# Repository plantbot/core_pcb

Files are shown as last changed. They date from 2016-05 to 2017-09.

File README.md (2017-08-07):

# Open Plantbot

Because growing plants is hard work and nobody ain't got no time for that anymore. This project was started after I managed to kill a plant my mother got me for my birthday last year because it was "unkillable". Ha.

This project aims to build an open source tool that provides environmental sensors for regular house plants as well as hydroponic systems.

Monitoring can either be done locally or via a "cloud" or not at all with add-on ports for pumps and future expansions (or your own?).

The goal is to eventually provide a block-based programming interface so that even people who don't enjoy writing C code (tzzz...who doesn't? :P) can customise their plantbot to do what they want.

### Current specs

Here is a list of current specs with notes about how they integrate/ work

1x Wifi enabled microprocessor

 - Can be programmed via RX/TX serial lines
 - USB/ OTA programming will be added later

4x Analog sensor mounts (for temperature, soil moisture, light, ...)

 - Variable gain amplifier can be used on a per-channel basis
 - Signal offset results in optimal reading per sensor type
 
2x I²C expansion ports for additional sensors or expansions

16-pin shield header for user (or future) expansion boards

Low-power sleep mode for the entire board/ expansion circuitry

### Current state

The board was re-designed recently in Rev A2. Prototypes were ordered and partially assembled. Further testing on the board layout and circuit design needs to be performed.

The firmware is largely unwritten.

Following are some pictures. Enjoy :)

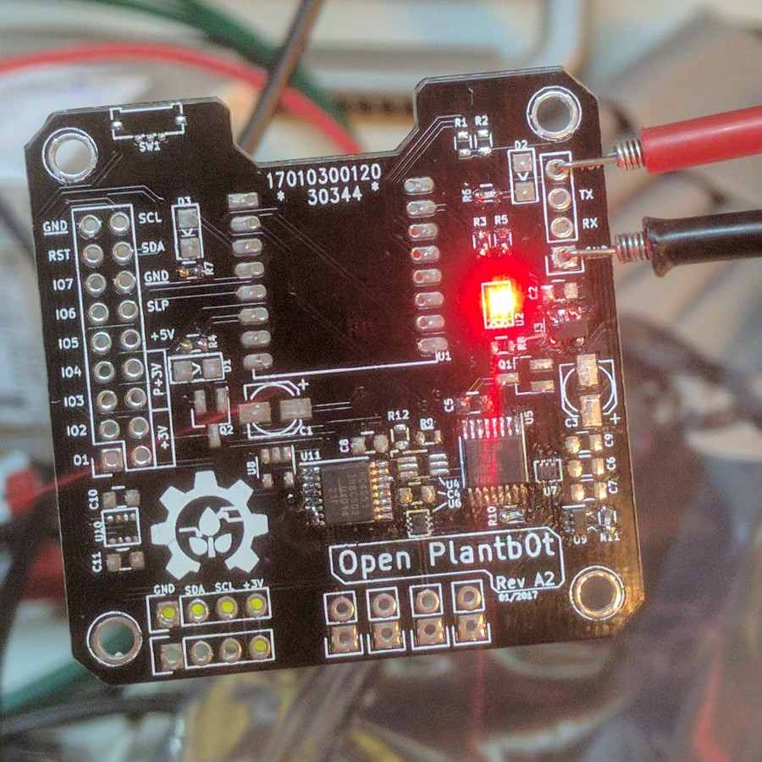
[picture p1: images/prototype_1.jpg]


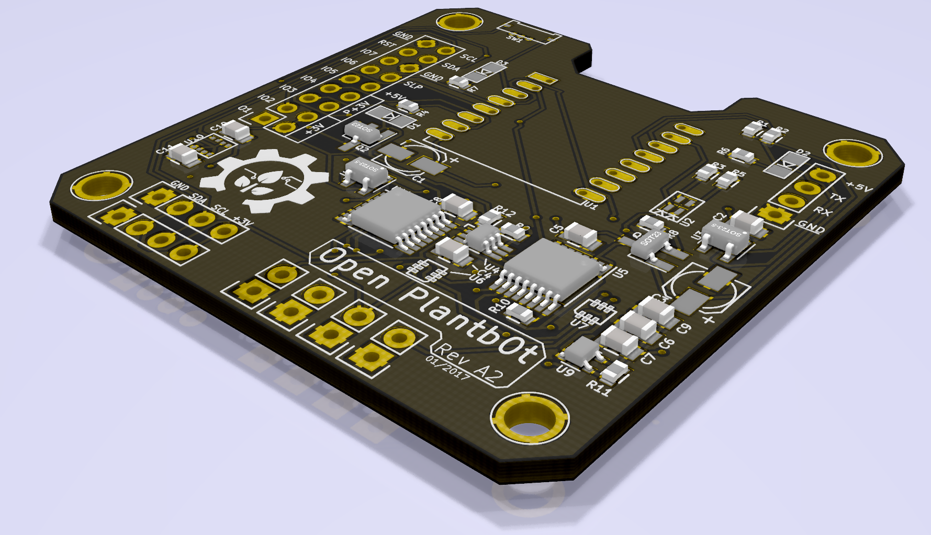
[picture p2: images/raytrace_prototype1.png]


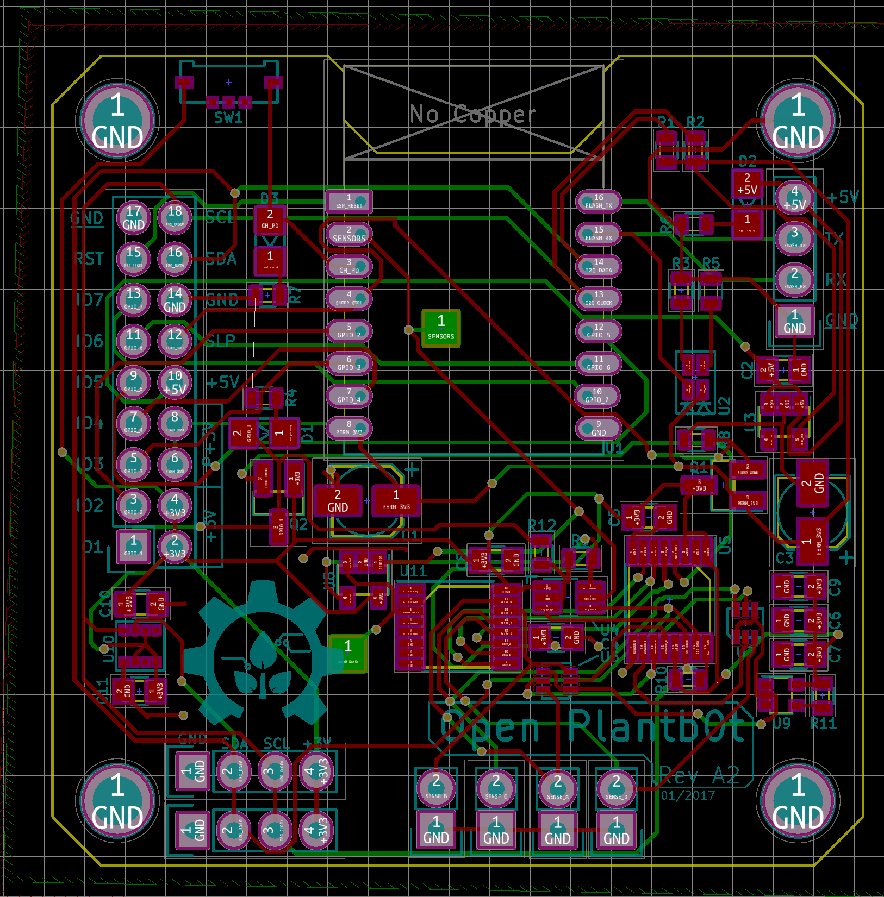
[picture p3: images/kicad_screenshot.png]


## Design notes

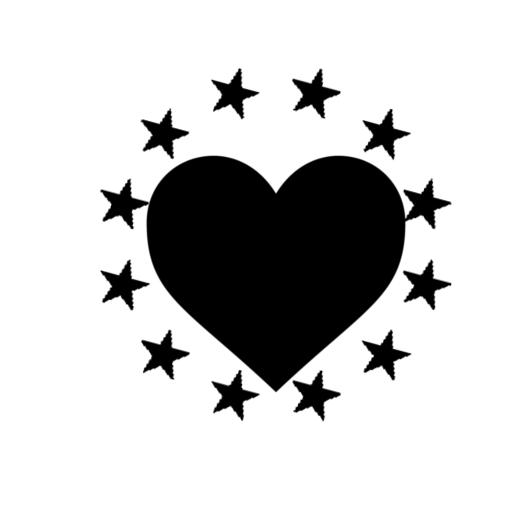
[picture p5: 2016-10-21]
docs/love_eu.png

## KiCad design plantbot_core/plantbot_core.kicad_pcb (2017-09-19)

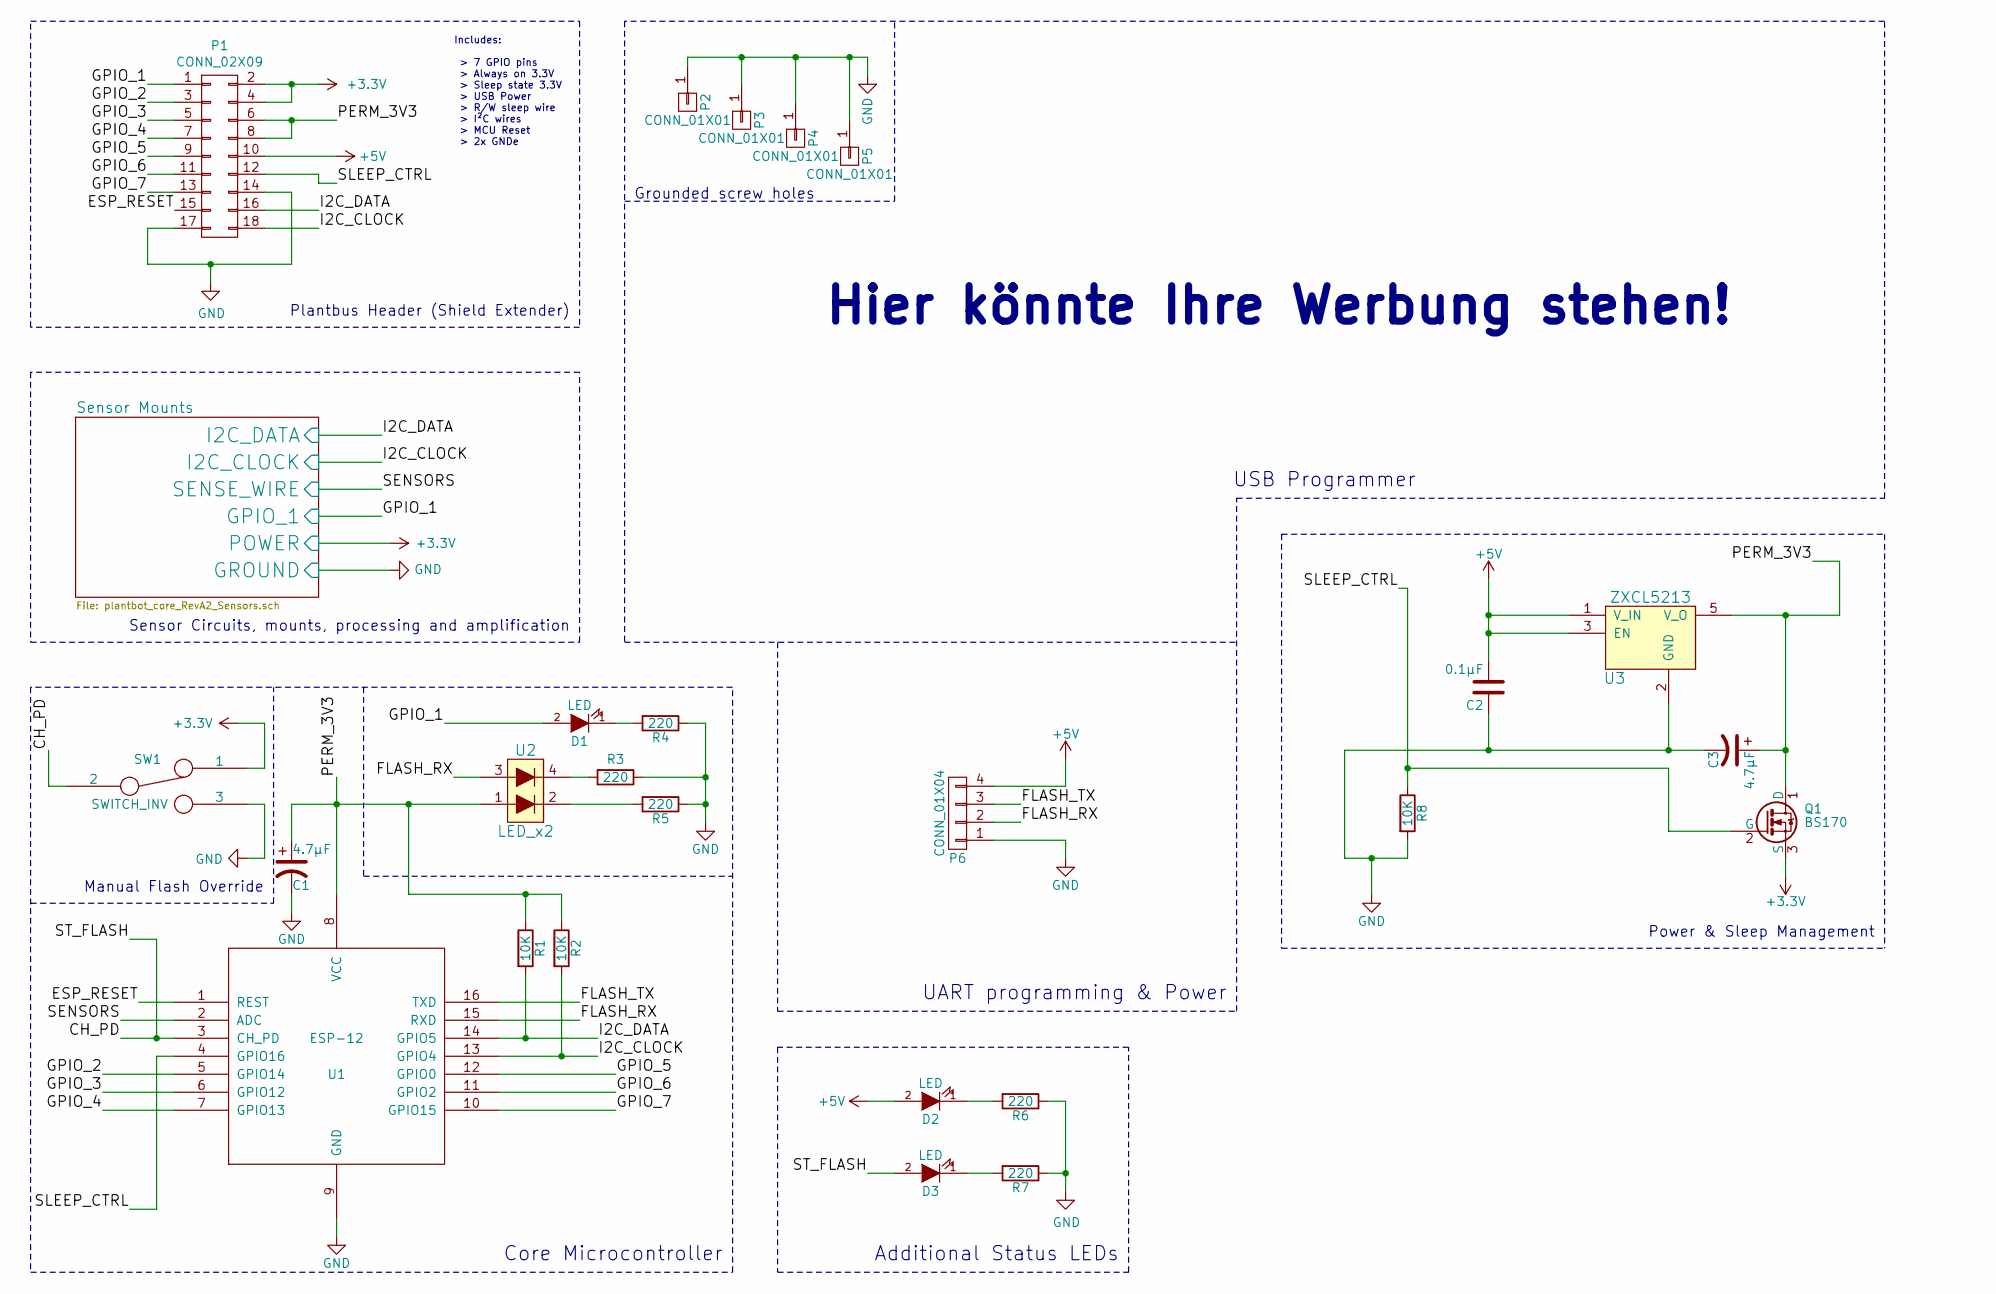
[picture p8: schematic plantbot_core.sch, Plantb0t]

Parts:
C1, C3: 4.7µF; c_elec_4x4.5
C2: 0.1µF; C_0805
D1, D2, D3: LED; knightbright_3216
P1: CONN_02X09; Socket_Strip_Straight_2x09
P2, P3, P4, P5: CONN_01X01; 1pin
P6: CONN_01X04; Socket_Strip_Straight_1x04
Q1: BS170; SOT-23_Handsoldering
R1, R2, R8: 10K; R_0603
R3, R4, R5, R6, R7: 220; R_0603
SW1: SWITCH_INV; SSAJ120100
U1: ESP-12
U2: LED_x2; SML-521
U3: ZXCL5213; SOT-23-5

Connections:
+3V3: P1.2, P1.4, Q1.3 (S), SW1.1; also elsewhere on the board
+5V: C2.2, D2.2 (A), P1.10, P6.4, U3.1 (V_IN), U3.3 (EN)
/CH_PD: D3.2 (A), SW1.2, U1.3 (CH_PD)
/ESP_RESET: P1.15, U1.1 (REST)
/FLASH_RX: P6.2, U1.15 (RXD), U2.3
/FLASH_TX: P6.3, U1.16 (TXD)
/GPIO_1: D1.2 (A), P1.1; also elsewhere on the board
/GPIO_2: P1.3, U1.5 (GPIO14)
/GPIO_3: P1.5, U1.6 (GPIO12)
/GPIO_4: P1.7, U1.7 (GPIO13)
/GPIO_5: P1.9, U1.12 (GPIO0)
/GPIO_6: P1.11, U1.11 (GPIO2)
/GPIO_7: P1.13, U1.10 (GPIO15)
/I2C_CLOCK: P1.18, R2.2, U1.13 (GPIO4); also elsewhere on the board
/I2C_DATA: P1.16, R1.2, U1.14 (GPIO5); also elsewhere on the board
/PERM_3V3: C1.1, C3.1, P1.6, P1.8, Q1.1 (D), R1.1, R2.1, U1.8 (VCC), U2.1, U3.5 (V_O)
/SENSORS: U1.2 (ADC); also elsewhere on the board
/SLEEP_CTRL: P1.12, Q1.2 (G), R8.1, U1.4 (GPIO16)
GND: C1.2, C2.1, C3.2, P1.14, P1.17, P2.1, P3.1, P4.1, P5.1, P6.1, R3.1, R4.1, R5.1, R6.1, R7.1, R8.2, SW1.3, U1.9 (GND), U3.2 (GND); also elsewhere on the board
unnamed: D1.1 (K), R4.2
unnamed: D2.1 (K), R6.2
unnamed: D3.1 (K), R7.2
unnamed: R3.2, U2.4
unnamed: R5.2, U2.2

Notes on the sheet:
Sensor Circuits, mounts, processing and amplification
Power & Sleep Management
Plantbus Header (Shield Extender)
UART programming & Power
USB Programmer
Manual Flash Override
Core Microcontroller
Additional Status LEDs
Includes: > 7 GPIO pins > Always on 3.3V > Sleep state 3.3V > USB Power > R/W sleep wire > I²C wires > MCU Reset > 2x GNDe
Grounded screw holes
Hier könnte Ihre Werbung stehen!

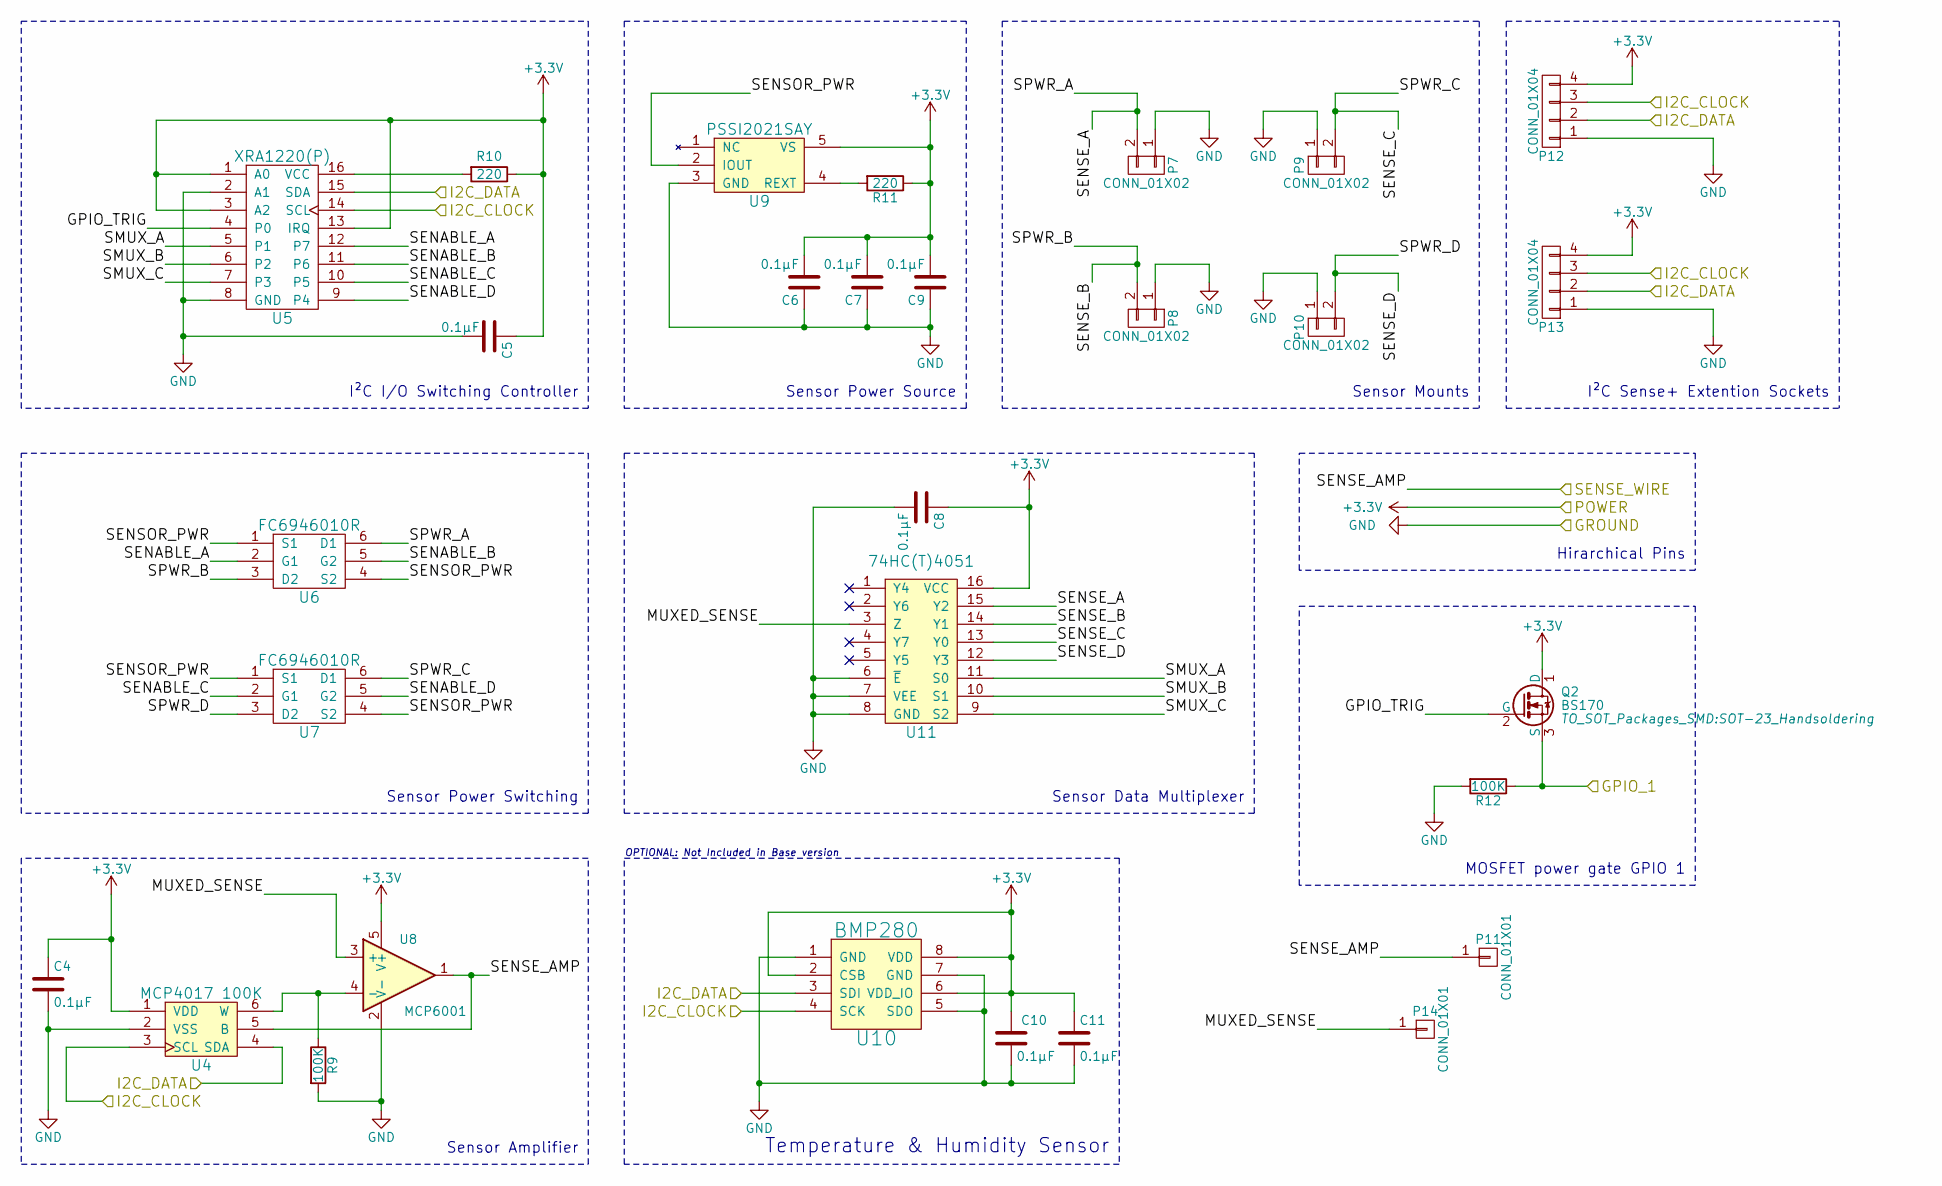
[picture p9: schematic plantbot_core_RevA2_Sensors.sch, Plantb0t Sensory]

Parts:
C4, C5, C6, C7, C8, C9, C10, C11: 0.1µF; C_0805
P7, P8, P9, P10: CONN_01X02; Socket_Strip_Straight_1x02
P11, P14: CONN_01X01; 1pin-SMD
P12, P13: CONN_01X04; Socket_Strip_Straight_1x04
Q2: BS170; SOT-23_Handsoldering
R9, R12: 100K; R_0603
R10, R11: 220; R_0603
U4: MCP4017 100K; SC-70-6_Handsoldering
U5: XRA1220(P); TSSOP-16_4.4x5mm_Pitch0.65mm
U6, U7: FC6946010R; sot666
U8: MCP6001; SOT-23-5
U9: PSSI2021SAY; SOT-353
U10: BMP280; BME280
U11: 74HC(T)4051; TSSOP-16_4.4x5mm_Pitch0.65mm

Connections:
+3V3: C4.1, C5.1, C6.2, C7.2, C8.1, C9.2, C10.1, C11.1, P12.4, P13.4, Q2.1 (D), R10.1, R11.1, U4.1 (VDD), U5.1 (A0), U5.3 (A2), U5.13 (IRQ), U8.5 (V+), U9.5 (VS), U10.2 (CSB), U10.6 (VDD_IO), U10.8 (VDD), U11.16 (VCC); also elsewhere on the board
/GPIO_1: Q2.3 (S), R12.1; also elsewhere on the board
/I2C_CLOCK: P12.3, P13.3, U4.3 (SCL), U5.14 (SCL), U10.4 (SCK); also elsewhere on the board
/I2C_DATA: P12.2, P13.2, U4.4 (SDA), U5.15 (SDA), U10.3 (SDI); also elsewhere on the board
/SENSORS: P11.1, U4.5 (B), U8.1; also elsewhere on the board
/Sensor Mounts/GPIO_TRIG: Q2.2 (G), U5.4 (P0)
/Sensor Mounts/MUXED_SENSE: P14.1, U8.3 (+), U11.3 (Z)
/Sensor Mounts/SENABLE_A: U5.12 (P7), U6.2 (G1)
/Sensor Mounts/SENABLE_B: U5.11 (P6), U6.5 (G2)
/Sensor Mounts/SENABLE_C: U5.10 (P5), U7.2 (G1)
/Sensor Mounts/SENABLE_D: U5.9 (P4), U7.5 (G2)
/Sensor Mounts/SENSE_A: P7.2, U6.6 (D1), U11.15 (Y2)
/Sensor Mounts/SENSE_B: P8.2, U6.3 (D2), U11.14 (Y1)
/Sensor Mounts/SENSE_C: P9.2, U7.6 (D1), U11.13 (Y0)
/Sensor Mounts/SENSE_D: P10.2, U7.3 (D2), U11.12 (Y3)
/Sensor Mounts/SENSOR_PWR: U6.1 (S1), U6.4 (S2), U7.1 (S1), U7.4 (S2), U9.2 (IOUT)
/Sensor Mounts/SMUX_A: U5.5 (P1), U11.11 (S0)
/Sensor Mounts/SMUX_B: U5.6 (P2), U11.10 (S1)
/Sensor Mounts/SMUX_C: U5.7 (P3), U11.9 (S2)
GND: C4.2, C5.2, C6.1, C7.1, C8.2, C9.1, C10.2, C11.2, P7.1, P8.1, P9.1, P10.1, P12.1, P13.1, R9.2, R12.2, U4.2 (VSS), U5.2 (A1), U5.8 (GND), U8.2 (V-), U9.3 (GND), U10.1 (GND), U10.5 (SDO), U10.7 (GND), U11.6 (~E), U11.7 (VEE), U11.8 (GND); also elsewhere on the board
unnamed: R9.1, U4.6 (W), U8.4 (-)
unnamed: R10.2, U5.16 (VCC)
unnamed: R11.2, U9.4 (REXT)

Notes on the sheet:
I²C I/O Switching Controller
Sensor Power Switching
Sensor Power Source
Sensor Data Multiplexer
Sensor Mounts
Sensor Amplifier
Hirarchical Pins
I²C Sense+ Extention Sockets
Temperature & Humidity Sensor
OPTIONAL: Not Included in Base version
MOSFET power gate GPIO 1

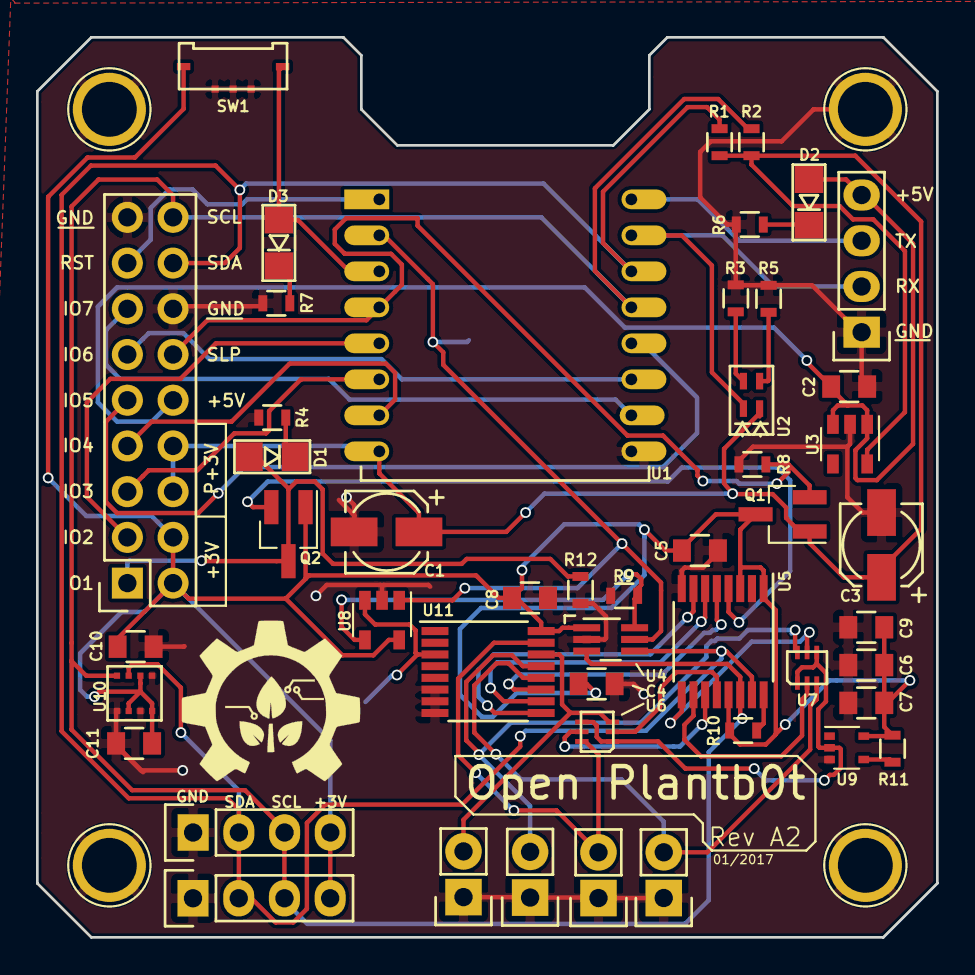
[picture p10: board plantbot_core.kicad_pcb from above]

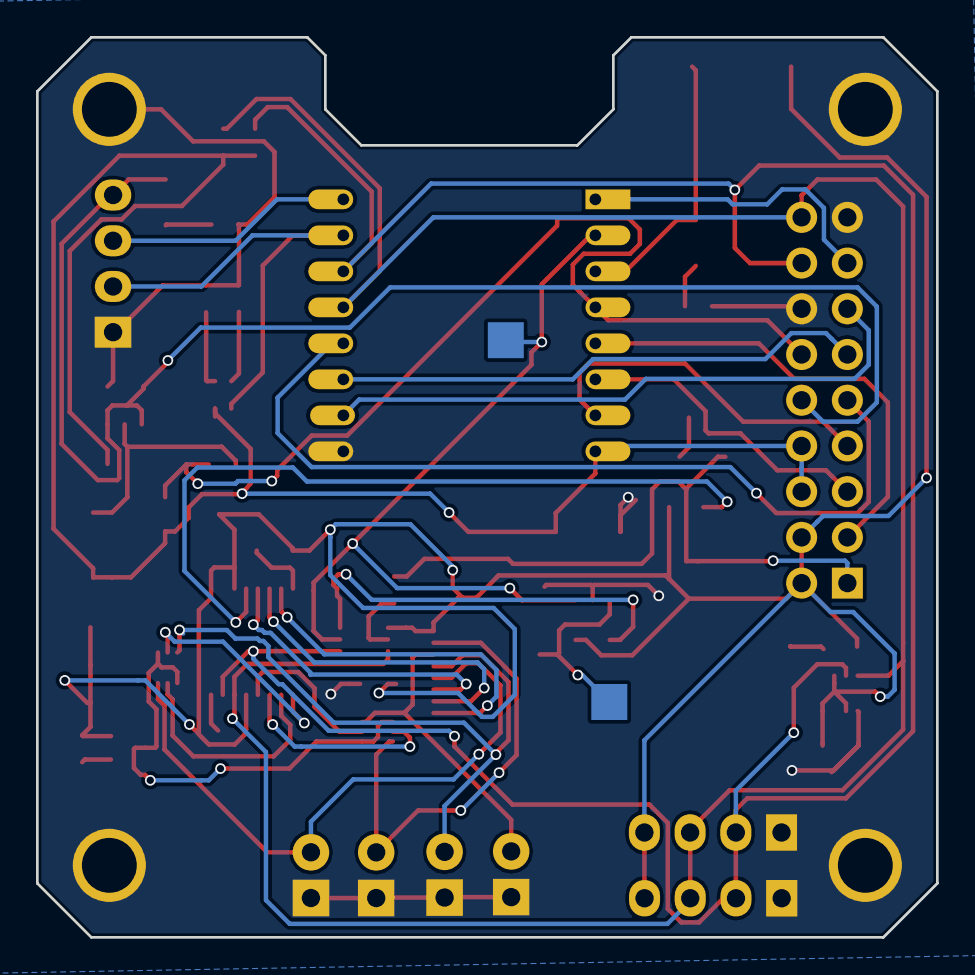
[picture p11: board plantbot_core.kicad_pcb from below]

Board: 2 copper layers, 50.0 x 50.0 mm, 54 parts (2 on the bottom side), 41 nets.

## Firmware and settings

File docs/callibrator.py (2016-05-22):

import serial
import time

ser = serial.Serial('/dev/ttyACM0', 9600)

print("#### STARTING READ ####")

while 1:
    try:
        serial_line = ser.readline()
    except:
        print("Some Error")

    # Write the data to a file
    with open("moisture.data", "a") as myfile:
        myfile.write("%s\n" % serial_line.strip())
    print("Reading: %s" % serial_line.strip())
    # time.sleep(1)

ser.close()

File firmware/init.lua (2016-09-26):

id=0  -- need this to identify (software) IC2 bus?
sda=4 -- connect to pin GPIO0
scl=3 -- connect to pin GPIO2
device_addr = 0x0

-- initialize i2c with our id and pins in slow mode :-)
i2c.setup(id,sda,scl,i2c.SLOW)

-- user defined function: read from reg_addr content of dev_addr
function read_reg(dev_addr, reg_addr)
     i2c.start(id)
     i2c.address(id, dev_addr ,i2c.TRANSMITTER)
     i2c.write(id,reg_addr)
     i2c.stop(id)
     i2c.start(id)
     i2c.address(id, dev_addr,i2c.RECEIVER)
     c=i2c.read(id,1)
     i2c.stop(id)
     return c
end

print("Scanning I2C Bus")
for i=0,127 do
     if (string.byte(read_reg(i, 0))==0) then
     print("Device found at address "..string.format("%02X",i))
     device_addr = i
     end
end

-- Function that writes a byte to the currently enabled address
-- Requires some global scope to work properly!
function write_byte(byte)
    i2c.address(id, device_addr, i2c.TRANSMITTER)
    i2c.write(id, byte)
end


i2c.start(id)

write_byte(1)

i2c.stop(id)

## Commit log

2016-03-28 Adding initial project files.
    [hydrobot.kicad_pcb, hydrobot.sch]
2016-03-29 Fleshing out Revision A of the PCB.
    [flowerbot.kicad_pcb, flowerbot.sch, hydrobot.kicad_pcb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]
2016-03-29 Adding more silkscreen and sensor multiplexing.
    [flowerbot.kicad_pcb, flowerbot.sch]
2016-03-29 Adding lots of gerber files, some new pictures, etc.
    [flowerbot-B.Cu.gbr, flowerbot-B.Mask.gbr, flowerbot-B.SilkS.gbr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]
2016-05-24 Cleaning up Repository.
    [Bill of Materials.ods, flowerbot.kicad_pcb, flowerbot.sch]
2016-06-18 Adding research material and schematics for the Rev A2 board.
    [Bill of Materials.ods, flowerbot.kicad_pcb, flowerbot.sch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]
2016-09-26 Updating a lot of stuff...
    [Bill of Materials.ods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]
2016-09-29 Loading in new kookie libs
    Updating Bill of Material for capacitors
    [Bill of Materials.ods, plantb0t.sch, plantb0t_RevA2_Sensors.sch]
2016-10-01 Starting Rev A2 board routing
    [plantb0t.kicad_pcb, plantb0t.sch, plantb0t_RevA2_Sensors.sch]
2016-10-17 Starting routing from scratch
    [_saved_plantb0t.sch, plantb0t.kicad_pcb, plantb0t_RevA2_Sensors.sch]
2016-10-17 Fiddling with the 5V plane for decoupling around the USB programmer
    [plantb0t.kicad_pcb]
2016-10-17 Adding a few GPIO pins to the header and wiring up I²C expander sockets
    [plantb0t.kicad_pcb]
2016-10-18 Moving analog section and adding power gating
    [plantb0t.kicad_pcb]
2016-10-18 Correcting a wire issue around bosch sensor Finishing basic routing I²C goes through VIAS. Is that an issue?
    [_saved_plantb0t.sch, plantb0t.kicad_pcb, plantb0t.sch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]
2016-10-18 Tweaking the ground plane and fixing missing traces
    [plantb0t.kicad_pcb]
2016-10-18 Finishing up board Revision A 2.0
    [plantb0t.kicad_pcb]
2016-10-21 Majorly updating the board. Moving some components. Changing the Plantbot logo \o/
    [plantb0t.kicad_pcb, plantb0t.sch, plantb0t_RevA2_Sensors.sch]
2017-01-01 Updating a bunch of project files to the state that went into production on 2017-01-01
    [flowerbot-B.Cu.gbr, flowerbot-B.Mask.gbr, flowerbot-B.SilkS.gbr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]
2017-03-29 Moving documentation over to fodt. Adding a bunch of stuff. Merging to master because yolo
    [Bill of Materials.ods, plantb0t.sch, plantb0t_RevA2_Sensors.sch]
2017-08-07 Renaming project stuff
    [plantbot_core.kicad_pcb, plantbot_core.sch, plantbot_core_RevA2_Sensors.sch]
2017-09-19 Fixing some KiCad issues (I think)
    [plantbot_core.kicad_pcb, plantbot_core.sch, plantbot_core_RevA2_Sensors.sch]
